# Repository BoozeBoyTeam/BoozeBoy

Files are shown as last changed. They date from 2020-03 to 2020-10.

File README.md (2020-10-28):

# BoozeBoy: Smart Speed Rail

# Abstract
Many bars and restaurants take inventory of their supplies after a set time period, sometimes weekly, bi-weekly, monthly, and some even once every couple of months. At the most basic procedure, this process involves counting the inventory at the beginning of a predetermined time period and then once again at the end of said time period. While this procedure may seem effective at first, it leaves a multi-billion dollar blind spot stemming from shrinkage. 

The problem with the basic approach is that while it keeps track of the input and the output, it fails to keep track of the details in between the input and the output inventory counts. Fortunately, this report explores a solution that seeks to provide insight into the inventory of such a business where it needs it the most: the service liquor bottle’s end-user life cycle. From the speed rail to the bartender to the shot glass to the customer and back to the speed rail. This is where the magic truly happens. The inbetween of the conventional time period: the input’s future and the output’s past. Introducing the solution of the present: a real-time monitoring system. The BoozeBoy: Smart Speed Rail.

The BoozeBoy: Smart Speed Rail is an IoT connected inventory system that monitors the real-time changes in the wide array of bottles commonly found at bars and restaurants and provides easy-to-understand user-friendly data visualization based on the monitored changes within each individual bottle. Our design monitors the changes in the liquor bottles found inside our custom speed rail via an embedded system that uses force sensors to monitor the predetermined bottle locations. The monitored data is then published via Message Queue Telemetry Transport to a cloud IoT platform where the data is then analyzed, visualized, and displayed to the end-user, thus allowing the end-user to observe the real-time statistics of the speed rail bottle inventory wirelessly and effortlessly. Finally, allowing access to data that encourages action in the moment - when it really matters - as opposed to the future once it is no longer as relevant. 

[Check Out Our Video](https://youtu.be/MDr-B3YPVlg)

# Note
Information regarding the hardware used will be provided soon.

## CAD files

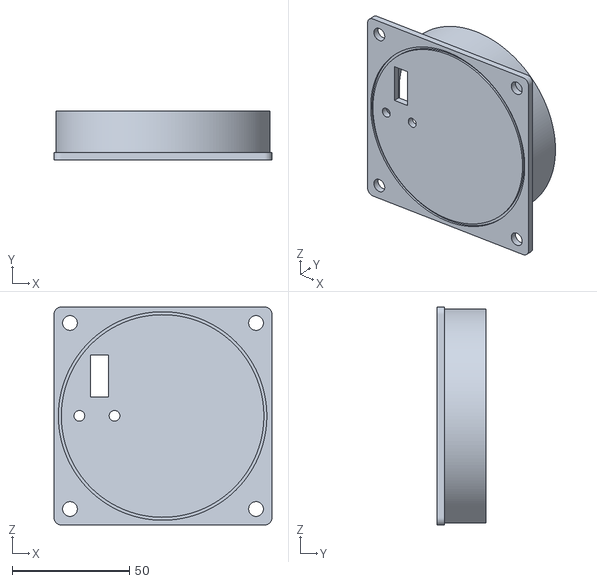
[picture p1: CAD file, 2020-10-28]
3D Models/Sensor Case/stl files/Bottom_Sensor_Base_v1_3.stl
93.0 x 20.9 x 93.0

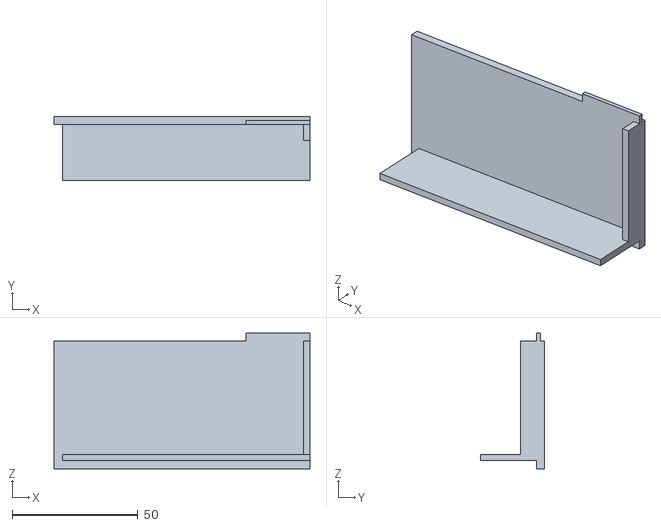
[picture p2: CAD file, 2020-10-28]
3D Models/Wire Housing/stl files/Wire Housing Wall vglue.stl
101.6 x 25.4 x 54.0

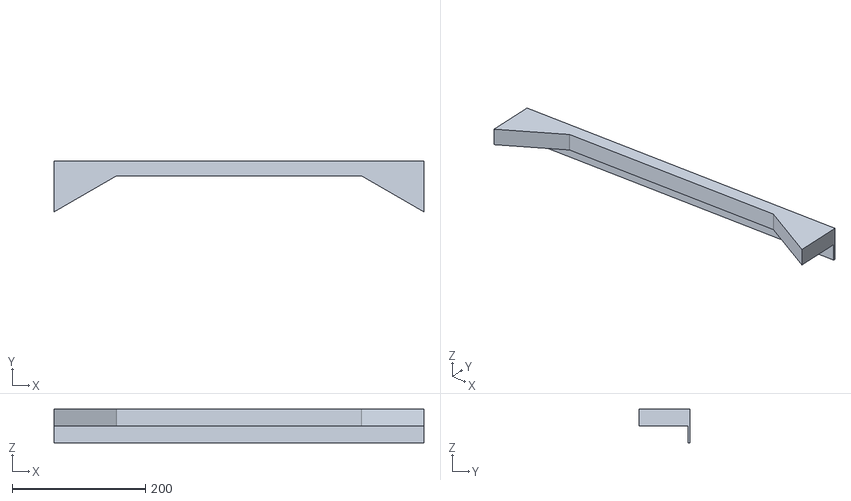
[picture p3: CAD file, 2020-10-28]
3D Models/Wire Housing/stl files/Wire Housing Lid vglue.stl
555.4 x 76.4 x 50.8

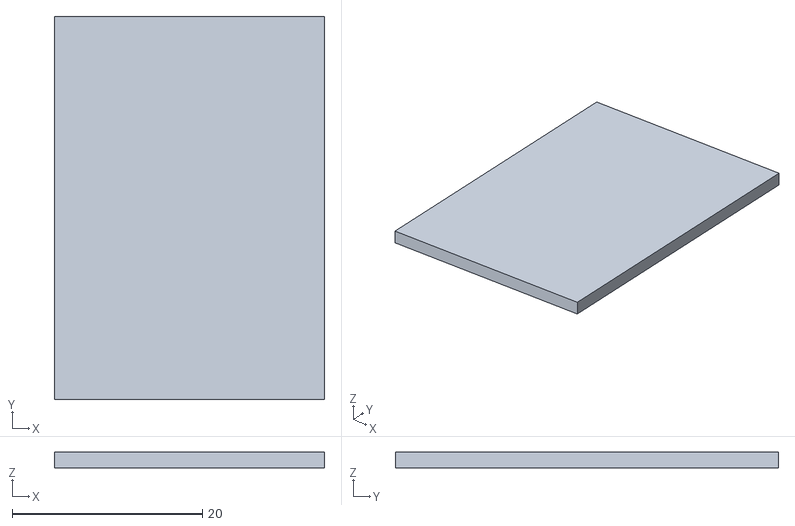
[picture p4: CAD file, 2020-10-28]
3D Models/Sensor Case/stl files/HX711 Mount Lid v1.2.stl
28.4 x 40.2 x 1.66

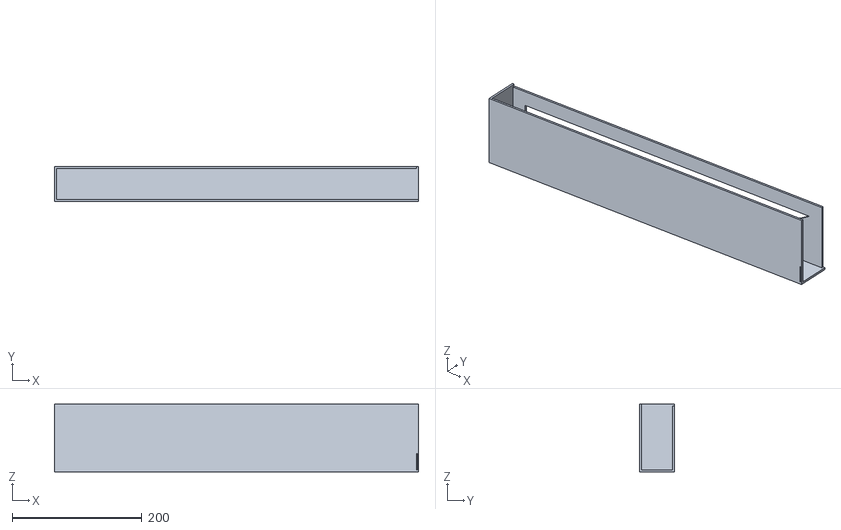
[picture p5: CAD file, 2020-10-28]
3D Models/Wire Housing/stl files/Wire Housing No Support Struct vglue.stl
562.0 x 54.0 x 104.8

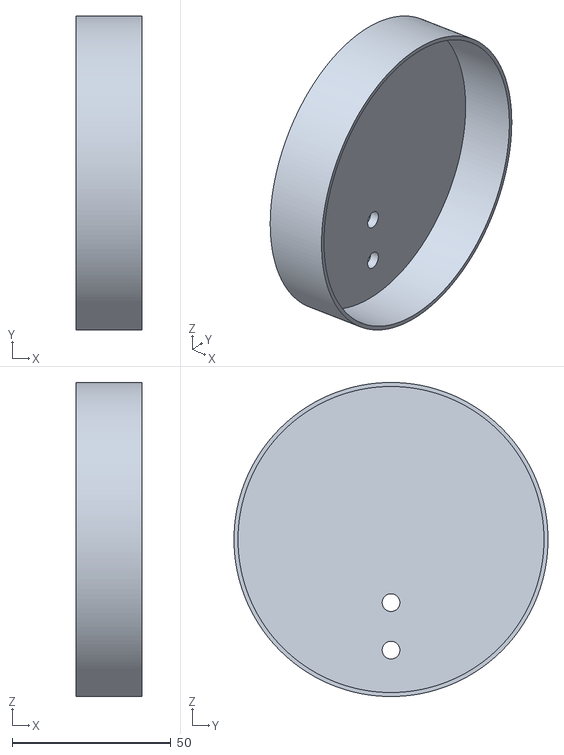
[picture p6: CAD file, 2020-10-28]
3D Models/Sensor Case/stl files/Top Sensor Base v1.2.stl
20.9 x 99.0 x 99.1

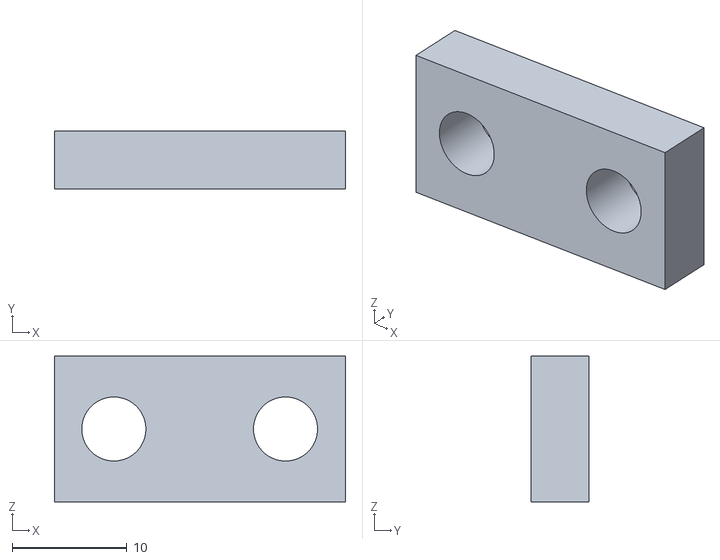
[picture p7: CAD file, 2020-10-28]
3D Models/Sensor Case/stl files/Rectangular Top Washer v1.2.stl
25.4 x 5.08 x 12.7

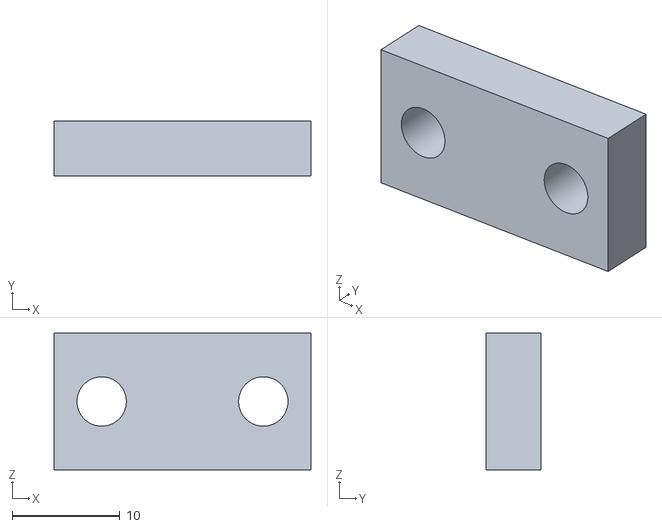
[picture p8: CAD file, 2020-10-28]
3D Models/Sensor Case/stl files/Rectangular Bottom Washer v1.2.stl
23.8 x 5.08 x 12.7

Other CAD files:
3D Models/Sensor Case/Inventor/Bottom Sensor Base v1.3.ipt
3D Models/Sensor Case/Inventor/HX711 Mount Lid v1.2.ipt
3D Models/Sensor Case/Inventor/Rectangular Bottom Washer v1.2.ipt
3D Models/Sensor Case/Inventor/Rectangular Top Washer v1.2.ipt
3D Models/Sensor Case/Inventor/Top Sensor Base v1.2.ipt
3D Models/Wire Housing/Inventor/Wire Housing Lid vglue.ipt
3D Models/Wire Housing/Inventor/Wire Housing No Support Struct vglue.ipt
3D Models/Wire Housing/Inventor/Wire Housing Wall vglue.ipt

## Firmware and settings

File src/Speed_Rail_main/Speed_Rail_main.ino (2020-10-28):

#include <WiFiClientSecure.h>
#include <Losant.h>

//Use your own compatible ssid, passwords, keys, etc. separately via header file 
#include "FinalAuthentication.h"
#include "HX711.h"

#define INIT_DELAY 2000

#define REPORT_INTERVAL 2000
#define REPORT_STANDARD_TIME_INCREMENT 100
#define SPEED_RAIL_SIZE 5
#define MIN_READING_THRESH 10 //grams less than this will be read as zero
#define NOISE_SPIKE_THRESH 50 //any increase above this indicates noise spike
#define NOISE_DELAY 1000 //incase of noise spike wait for the spike to leave

#define calibration_factor_s1 367.6414185 //366.5924072 
#define calibration_factor_s2 381.8397827 //381.8333130 
#define calibration_factor_s3 383.4008789 //382.7804565
#define calibration_factor_s4 369.7872314 //396.9192505 
#define calibration_factor_s5 391.1741333 //390.3388672 

#define D1  14
#define D2  26
#define D3  27
#define D4  25
#define D5  33

#define CLK   12

//unsigned long time;

void connect(void);
void reportWeight(String [], float []);
boolean noiseSpike(void);

WiFiClientSecure wifiClient;
LosantDevice device(LOSANT_DEVICE_ID);

HX711 speedrail[SPEED_RAIL_SIZE];
String sensorNames[SPEED_RAIL_SIZE] = {"S1","S2","S3","S4","S5"};
int dout[SPEED_RAIL_SIZE] = {D1, D2, D3, D4, D5};
float calFactor[SPEED_RAIL_SIZE] = {calibration_factor_s1, calibration_factor_s2,
calibration_factor_s3, calibration_factor_s4, calibration_factor_s5}; 

void setup() 
{
  Serial.begin(115200);
  delay(INIT_DELAY);
  connect(); 
  Serial.println("BoozeBoy: Smart Speed Rail demo");
  for(int i = 0; i < SPEED_RAIL_SIZE; i++)
  {
    speedrail[i].begin(dout[i], CLK);
    speedrail[i].set_scale(calFactor[i]); 
    speedrail[i].tare();
  }
}

int timeSinceLastRead = 0;

float readingsSum[SPEED_RAIL_SIZE] = {0.0, 0.0, 0.0, 0.0, 0.0};
int readingsCounter[SPEED_RAIL_SIZE] = {0, 0, 0, 0, 0};
float readingsAverage [SPEED_RAIL_SIZE] = {0.0, 0.0, 0.0, 0.0, 0.0};


float prevValueSnapshot[SPEED_RAIL_SIZE] = {0.0, 0.0, 0.0, 0.0, 0.0};
float current = 0.0;
boolean noiseFlag = false;

void loop() 
{
  bool toReconnect = false;

  if (WiFi.status() != WL_CONNECTED) 
  {
    Serial.println("Disconnected from WiFi");
    toReconnect = true;
  }

  if (!device.connected()) 
  {
    Serial.println("Disconnected from MQTT");
    Serial.println(device.mqttClient.state());
    toReconnect = true;
  }

  if (toReconnect) 
  {
    connect();
  }

  device.loop();
  
  for(int i = 0; i < SPEED_RAIL_SIZE; i++)
  {
     current = (float)abs(speedrail[i].get_units());
     
      if(noiseSpike(prevValueSnapshot[i], current, noiseFlag))
      {
        /*debugging prints
        Serial.println(current);
        Serial.println(prevValueSnapshot[i]);
        */
        Serial.println("Noise detected"); 
        delay(NOISE_DELAY);
        timeSinceLastRead += NOISE_DELAY;
        noiseFlag = true;
        i--;
      }
      else
      {
        /*debugging prints
        Serial.println(current);
        Serial.println(prevValueSnapshot[i]);
        */
        readingsSum[i] += current;
        readingsCounter[i]++;
        prevValueSnapshot[i] = current;
        noiseFlag = false;
      }
  }  
  
  if (timeSinceLastRead > REPORT_INTERVAL)
  {
    // Take the average reading over the last 15 seconds.

      for(int i = 0; i < SPEED_RAIL_SIZE; i++)
      {
        readingsAverage[i] = readingsSum[i]/((float)readingsCounter[i]);

        //Clear empty sensor noise floor
        if (readingsAverage[i] < MIN_READING_THRESH)
        {
          readingsAverage[i] = 0.0;
        }
      }
    
      //real-time check debugging prints
      for(int i = 0; i < SPEED_RAIL_SIZE; i++)
      {       
      Serial.print(sensorNames[i] + ": ");
      Serial.print(speedrail[i].get_units(), 3); //scale.get_units() returns a float
      Serial.print(" grams"); //You can change this to kg but you'll need to refactor the calibration_factor
      Serial.println();
      }
  
      reportWeight(sensorNames , readingsAverage);
      
     for(int i = 0; i < SPEED_RAIL_SIZE; i++)
     {
        readingsSum[i] = 0.0;
        readingsCounter[i] = 0; 
     }
     timeSinceLastRead = 0;
  } 
  delay(REPORT_STANDARD_TIME_INCREMENT);
  timeSinceLastRead += REPORT_STANDARD_TIME_INCREMENT;
}

void connect() 
{
  // Connect to Wifi.
  Serial.println();
  Serial.println();
  Serial.print("Connecting to ");
  Serial.println(WIFI_SSID);

  WiFi.begin(WIFI_SSID, WIFI_PASS);

  while (WiFi.status() != WL_CONNECTED) 
  {
    delay(1000);
    Serial.print(".");
  }

  Serial.println("");
  Serial.println("WiFi connected");
  Serial.println("IP address: ");
  Serial.println(WiFi.localIP());

  Serial.println();
  Serial.print("Connecting to Losant...");

  device.connectSecure(wifiClient, LOSANT_ACCESS_KEY, LOSANT_ACCESS_SECRET);

  //debugging
  while(!device.connected()) 
  {
    delay(500);
    Serial.println(device.mqttClient.state()); // HERE
    Serial.print(".");
  }
  Serial.println("Connected!");
  Serial.println("This device is now ready for use!");
}

void reportWeight(String * namesOfSensors, float * averageDataReadings) 
{
  String speedrailPayload; 
  for(int i = 0; i < SPEED_RAIL_SIZE; i++)
  {
    if(i == 0)
    {
      speedrailPayload += "{\"" + namesOfSensors[i] + "\": \"" + (String)averageDataReadings[i];
    }
    
    else if(i < SPEED_RAIL_SIZE - 1)
    {
      speedrailPayload += "\", \"" +namesOfSensors[i] + "\" : \"" + (String)averageDataReadings[i];
    }
  
    else
    {
      speedrailPayload += "\", \"" +namesOfSensors[i] + "\" : \"" + (String)averageDataReadings[i] + "\"}";
    }
  }
                        
    StaticJsonBuffer<200> jsonBuffer;
    JsonObject& root = jsonBuffer.parseObject(speedrailPayload);
    //debugging prints
    Serial.println(speedrailPayload);
    device.sendState(root);
  
}

boolean noiseSpike(float prevReading, float currentReading, boolean noiseFlagTriggered)
{
  
  if((abs(currentReading -  prevReading) > NOISE_SPIKE_THRESH) && !(noiseFlagTriggered))
  {
    return true;
  }
  return false;
}

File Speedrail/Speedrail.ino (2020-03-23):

#include <WiFiClientSecure.h>
#include <Losant.h>
#include "HX711.h"
#include "Authentication.h"

#define RAIL_SIZE 5
#define CLK 12

#define RANGE_BOUND 100000.0
#define VALIDATION_THRESHOLD 10 //arbitruary 

const char* SENSOR_ID[] = {"S1", "S2", "S3", "S4", "S5"};
const int DOUT[RAIL_SIZE] = {14, 27, 26, 25, 33};

/******************************** Default Calibration **************************/
float calFactors[RAIL_SIZE] = {396.9192505,          //sensor 1
                               396.9192505,          //sensor 2
                               396.9192505,          //sensor 3
                               396.9192505,          //sensor 4
                               396.9192505};         //sensor 5
/*******************************************************************************/

/******************************** Default Zero Offset **************************/
float zOffset[RAIL_SIZE] = {0,         //sensor 1
                           0,          //sensor 2
                           0,          //sensor 3
                           0,          //sensor 4
                           0};         //sensor 5
/*******************************************************************************/

/*************************** Calibration Functions *****************************/
void speedrail_calibration(void);

void set_calibration_factor(float calibrationFactor);
float find_calibration_factor(float knownMeasurement);
float get_calibration_factor(void);  
/*******************************************************************************/

/********************************* WIFI Functions ******************************/
void connect(void);
/*******************************************************************************/

/************************* Losant Reporting Functions **************************/
void reportWeight(float weight, int tag = 0);
void reportWeight(float weight[]);
void speedrail_init(void);
void read_values(void);
/*******************************************************************************/

/* WiFi credentials. No longer displayed here. Create seperate header file.
const char* WIFI_SSID = "XXX";
const char* WIFI_PASS = "XXX";

// Losant credentials.
const char* LOSANT_DEVICE_ID = "XXX";
const char* LOSANT_ACCESS_KEY = "XXX";
const char* LOSANT_ACCESS_SECRET = "XXX";
*/

WiFiClientSecure wifiClient;

LosantDevice device(LOSANT_DEVICE_ID);

HX711 speedrail[5];

int timeSinceLastRead = 0;
float weightSum = 0.0;
int weightCount = 0;


/*********************** Setup Function *******************************************/
void setup() 
{ 
  Serial.begin(115200); 
  delay(2000); //gives 
  Serial.println("BoozeBoy: Speedrail Demo");
  
  connect(); 

  if((speedrail never used before) || (user wants to recalibrate))
  {
    speedrail_calibration(); //recalibration occurs at push of button
  }
  else
  {
    speedrail_init(); //does not tare
  }
  
  Serial.println("Readings:");

}
/*******************************************************************************/


/****************************** Loop Function **********************************/
void loop() 
{
  bool toReconnect = false;

  if (WiFi.status() != WL_CONNECTED) {
    Serial.println("Disconnected from WiFi");
    toReconnect = true;
  }

  if (!device.connected()) {
    Serial.println("Disconnected from MQTT");
    Serial.println(device.mqttClient.state());
    toReconnect = true;
  }

  if (toReconnect) {
    connect();
  }

  device.loop();

  weightSum += (float)(abs(speedrail[0].get_units()));
  weightCount++;
   //to report every 15 seconds
   if (timeSinceLastRead > 2000) {
    // Take the average reading over the last 15 seconds.
    float averageWeight = weightSum/((float)weightCount);

    // The tmp36 documentation requires the -0.5 offset, but during
    // testing while attached to the Feather, all tmp36 sensors
    // required a -0.52 offset for better accuracy.


    Serial.print("Reading: ");
    Serial.print(speedrail[0].get_units(), 3); //scale.get_units() returns a float
    Serial.print(" grams"); //You can change this to kg but you'll need to refactor the calibration_factor
    Serial.println();


    reportWeight(averageWeight);

    timeSinceLastRead = 0;
    weightSum = 0.0;
    weightCount = 0;
  }
  
//testing
 Serial.print("Reading: ");
    Serial.print(speedrail[0].get_units(), 3); //scale.get_units() returns a float
    Serial.print(" grams"); //You can change this to kg but you'll need to refactor the calibration_factor
    Serial.println();

    
  delay(100);
  timeSinceLastRead += 100;
}
/*******************************************************************************/

/**
 * WIFI CONNECT FUNCTION
 * CONNECTS TO GIVEN SSID AND PASSWORD
 * REPORTS IN SERIAL MONTIOR CONNECTION STATUS
 */

void connect() 
{
  // Connect to Wifi.
  Serial.println();
  Serial.println();
  Serial.print("Connecting to ");
  Serial.println(WIFI_SSID);

  WiFi.begin(WIFI_SSID, WIFI_PASS);

  while (WiFi.status() != WL_CONNECTED)
  {
    delay(1000);
    Serial.print(".");
  }

  Serial.println("");
  Serial.println("WiFi connected");
  Serial.println("IP address: ");
  Serial.println(WiFi.localIP());

  Serial.println();
  Serial.print("Connecting to Losant...");

  device.connectSecure(wifiClient, LOSANT_ACCESS_KEY, LOSANT_ACCESS_SECRET);

  //debugging
  while(!device.connected()) 
  {
    delay(500);
    Serial.println(device.mqttClient.state()); // HERE
    Serial.print(".");
  }
  
  /*
  while (!device.connected()) {
    delay(500);
    Serial.print(".");
  }
  */
  
  Serial.println("Connected!");
  Serial.println("This device is now ready for use!");
}


/** FUNCTION TO CREATE JSON AND PUSH TO LOSANT 
 *  WEIGHT = CURRENT WEIGHT VALUE OF A LOAD cell
 *  TAG = LOAD CELL LOCATION IN THE RAIL
 */
void reportWeight(float weight, int tag = 0) // tag default  to 0 for testing 
{
  StaticJsonBuffer<200> jsonBuffer;
  JsonObject& root = jsonBuffer.createObject();
  root["weight"] = weight;
  root["tag"] = tag;
  device.sendState(root);
}
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

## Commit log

2020-02-08 Added Arduino JSON
2020-02-08 Added Arduino File
2020-02-08 Added Folder for Arduino Code to work nice
    Arduino ide requires a folder to contain the code.
2020-02-09 basic bugged AutoCalibration File included
    [Scale_AutoCalibration_v2.ino]
2020-02-09 Sample Commit to show collision resolution
    [Scale_AutoCalibration_v2.ino]
2020-03-23 Most Basic Demo Code Available
    Speedrail_Basic_Losant.ino holds functional demo code. This is not the final code; however, the bare minimum requirement has been met with this.
    (Note: individual calibration factors need to be updated before demo)
    Also:
    Aunthentication has been removed from all files and replaced by a local header file not included.
    [Scale_AutoCalibration_v2.ino, Scale_Working_Losant.ino, Speedrail.ino]
2020-03-23 Added Basic Calibration
    Basic Demo Ready Calibration
    Note: Sensor 4 Readings are faulty, I will have to recrimp Sensor 4 wires and re-test.
    Additionally, There are noise spikes that occur every minute or so on multiple sensors to give an arbitruary idea of a problem to resolve in the future. (I have graphs available in Google Drive showing the spikes)
    [Scale_AutoCalibration_v2.ino]
2020-04-15 Cleaner Code
    Cleaner Code/ Some Early Noise Smoothing
    [Speed_Rail_main.ino]
2020-04-16 Upward Noise Spikes Handled
    There are no more Upward Noise Spikes being sent
    [Speed_Rail_main.ino]
2020-04-16 All Noise has been handled
    Noise Spikes and Drops have been handled. Further Optimization on Thresholds and Noise Time Delay is possible. However, this works well already.
    [Speed_Rail_main.ino]
2020-10-28 3D Models added
    3D Models added
    [Bottom Sensor Base v1.3.ipt, Bottom_Sensor_Base_v1_3.stl, HX711 Mount Lid v1.2.ipt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]
